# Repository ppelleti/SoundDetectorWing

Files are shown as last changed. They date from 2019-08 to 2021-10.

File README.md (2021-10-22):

This repository contains [KiCad][1] 5 files for a [FeatherWing][2]
board which lets you plug in a [SparkFun Sound Detector][3] and use it
with a Feather.  It runs the Sound Detector at 5V, and then has
voltage dividers to convert the output signals to 3.3V, for use by the
Feather.

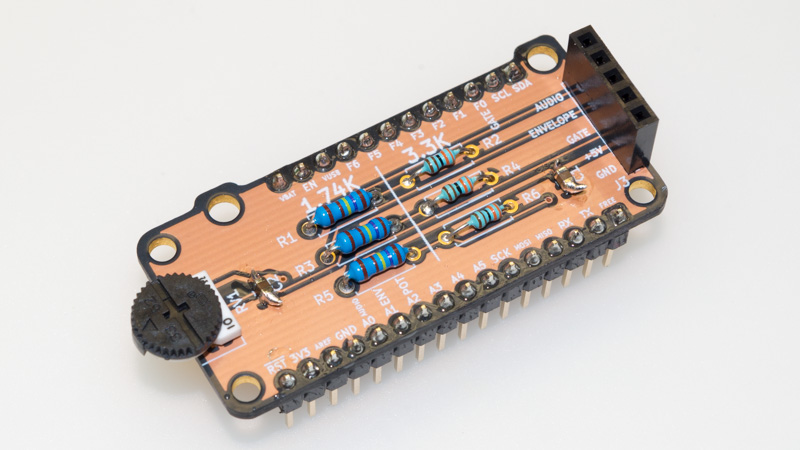
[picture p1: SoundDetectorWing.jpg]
Sound Detector FeatherWing


The "audio" analog signal is connected to feather pin A0, the
"envelope" analog signal is connected to feather pin A1, and the
"gate" digital signal is connected to the feather pin that
[I call F0][4].  There is also a potentiometer connected to feather
pin A2, which can be used, for example, if you want to implement an
adjustable threshold in software (rather than using the Sound
Detector's "gate" signal).

The board has three M2.5 mounting holes which should line up with the
Feather, and two M3 mounting holes which should line up with the Sound
Detector. There are optional places for two SMT decoupling capacitors.

SparkFun recommends running the Sound Detector at 5V, rather than
3.3V, so the Sound Detector is powered from the Feather's VUSB pin, to
get a solid 5V supply.  A consequence of this is that *this
FeatherWing will not work on battery power*; you must have USB plugged
in for power.

* [View schematic](SoundDetectorWing.pdf)
* [Order board on OSH Park][5] (photo shows the OSH Park "after dark" option)

## Bill of Materials

| Ref | Description | MPN | Digi-Key PN |
| --- | --- | --- | --- |
| C1, C2 | CAP CER 10UF 10V X5R 0805 | C0805C106K8PACTU | [399-4925-1-ND][C1] |
| J1 | 16-pin male header 2.54mm | | |
| J2 | 12-pin male header 2.54mm | | |
| J3 | CONN HDR 5POS 0.1 GOLD PCB | PPPC051LFBN-RC | [S7038-ND][J3] |
| R1, R3, R5 | RES 1.74K OHM 1/4W 1% AXIAL | MFR-25FBF52-1K74 | [1.74KXBK-ND][R1] |
| R2, R4, R6 | RES 3.3K OHM 1/4W 1% AXIAL | RNMF14FTC3K30 | [S3.3KCACT-ND][R2] |
| RV1 | POT 10K OHM THUMBWHEEL CERM ST | 3352T-1-103LF | [3352T-103LF-ND][RV1] |

[C1]: https://www.digikey.com/products/en?keywords=399-4925-1-ND
[J3]: https://www.digikey.com/products/en?keywords=S7038-ND
[R1]: https://www.digikey.com/products/en?keywords=1.74KXBK-ND
[R2]: https://www.digikey.com/products/en?keywords=S3.3KCACT-ND
[RV1]: https://www.digikey.com/products/en?keywords=3352T-103LF-ND

[1]: http://kicad.org/
[2]: https://learn.adafruit.com/adafruit-feather/feather-specification
[3]: https://www.sparkfun.com/products/12642
[4]: https://funwithsoftware.org/posts/2018-08-31-feather-ascii-art-pinout.html
[5]: https://oshpark.com/shared_projects/fDlbdMGa

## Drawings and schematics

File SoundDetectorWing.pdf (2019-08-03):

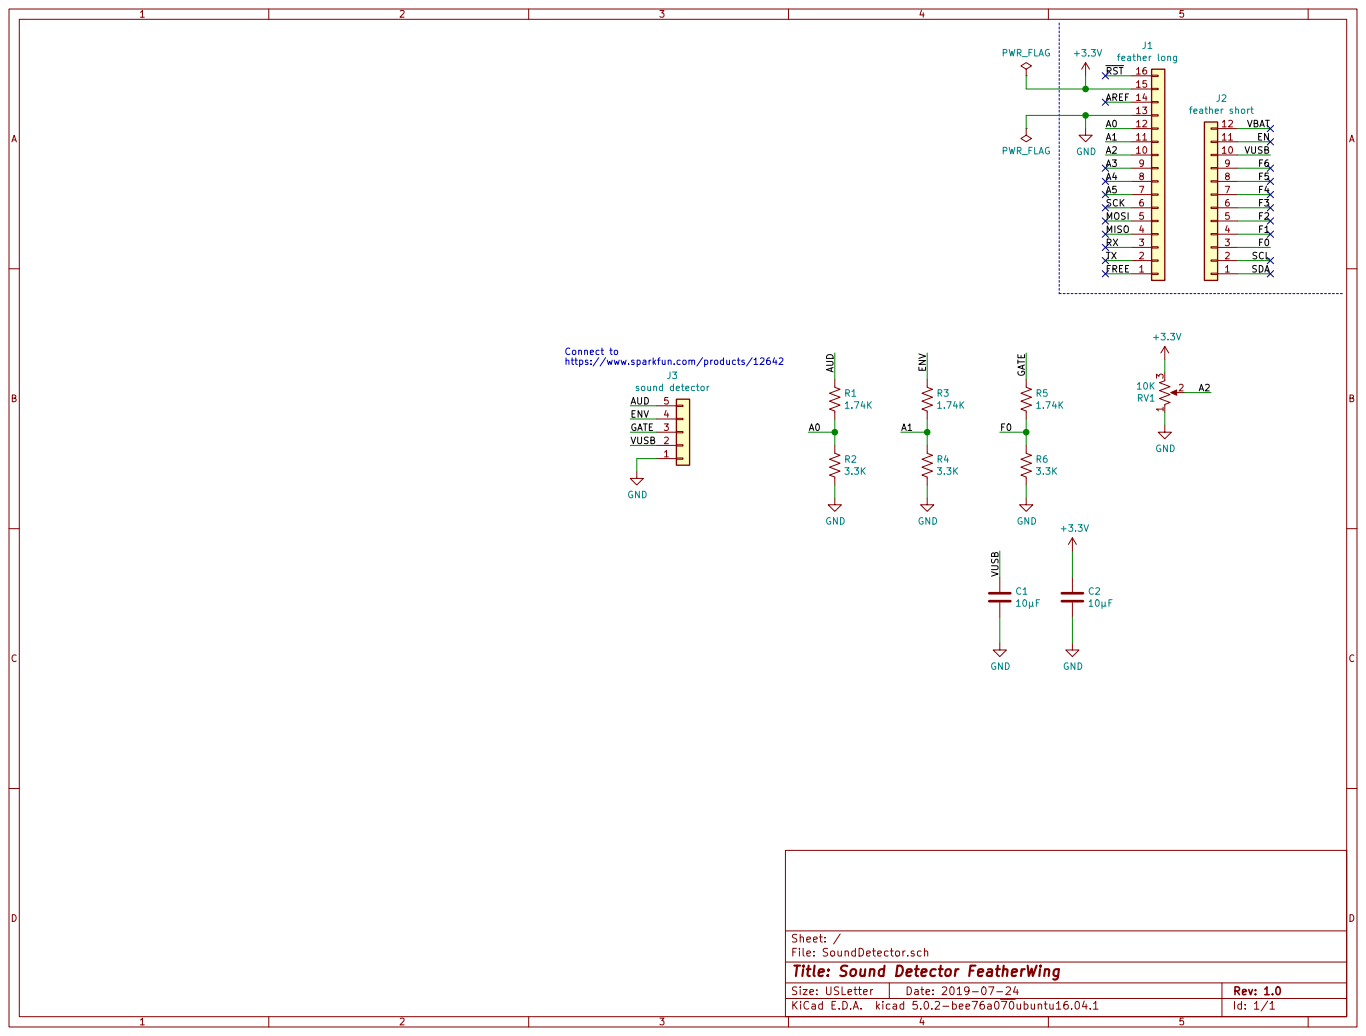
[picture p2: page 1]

+3.3V Connect to
https://www.sparkfun.com/products/12642
ENV GATE GND

File: SoundDetector.sch Sheet: /
Id: 1/1 Title: Sound Detector FeatherWing

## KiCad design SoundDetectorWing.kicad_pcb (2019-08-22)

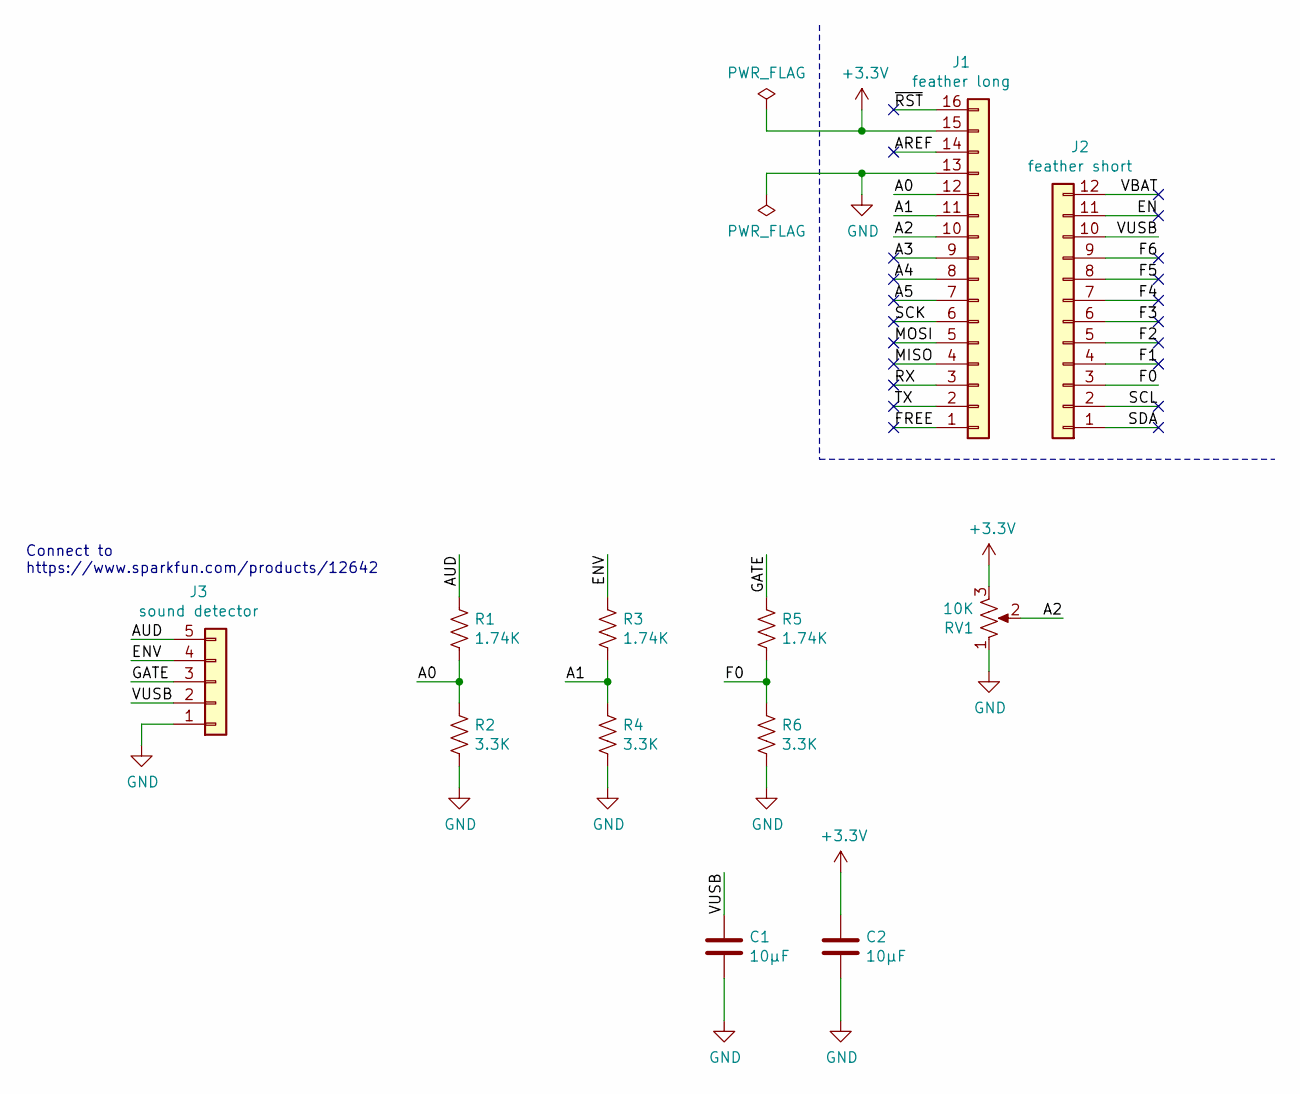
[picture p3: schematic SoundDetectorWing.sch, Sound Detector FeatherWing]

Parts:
C1, C2: 10μF; C_0805_2012Metric_Pad1.15x1.40mm_HandSolder; MPN C0805C106K8PACTU; Digi-Key_PN 399-4925-1-ND
J1: feather long; PinHeader_1x16_P2.54mm_Vertical
J2: feather short; PinHeader_1x12_P2.54mm_Vertical
J3: sound detector; PinSocket_1x05_P2.54mm_Vertical; MPN PPPC051LFBN-RC; Digi-Key_PN S7038-ND
R1, R3, R5: 1.74K; R_Axial_DIN0207_L6.3mm_D2.5mm_P7.62mm_Horizontal; MPN MFR-25FBF52-1K74; Digi-Key_PN 1.74KXBK-ND
R2, R4, R6: 3.3K; R_Axial_DIN0207_L6.3mm_D2.5mm_P7.62mm_Horizontal; MPN RNMF14FTC3K30; Digi-Key_PN S3.3KCACT-ND
RV1: 10K; Potentiometer_Bourns_3352T_Vertical; MPN 3352T-1-103LF; Digi-Key_PN 3352T-103LF-ND

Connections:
+3V3: C2.1, J1.15, RV1.3
/A0: J1.12, R1.2, R2.1
/A1: J1.11, R3.2, R4.1
/A2: J1.10, RV1.2
/A3: J1.9
/A4: J1.8
/A5: J1.7
/AREF: J1.14
/AUD: J3.5, R1.1
/EN: J2.11
/ENV: J3.4, R3.1
/F0: J2.3, R5.2, R6.1
/F1: J2.4
/F2: J2.5
/F3: J2.6
/F4: J2.7
/F5: J2.8
/F6: J2.9
/FREE: J1.1
/GATE: J3.3, R5.1
/MISO: J1.4
/MOSI: J1.5
/RX: J1.3
/SCK: J1.6
/SCL: J2.2
/SDA: J2.1
/TX: J1.2
/VBAT: J2.12
/VUSB: C1.1, J2.10, J3.2
/~RST: J1.16
GND: C1.2, C2.2, J1.13, J3.1, R2.2, R4.2, R6.2, RV1.1

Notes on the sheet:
Connect to https://www.sparkfun.com/products/12642

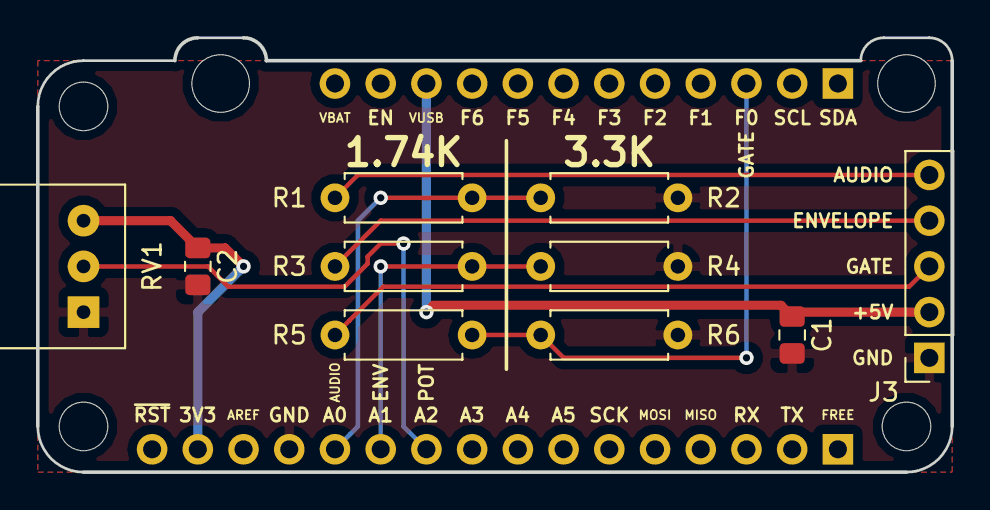
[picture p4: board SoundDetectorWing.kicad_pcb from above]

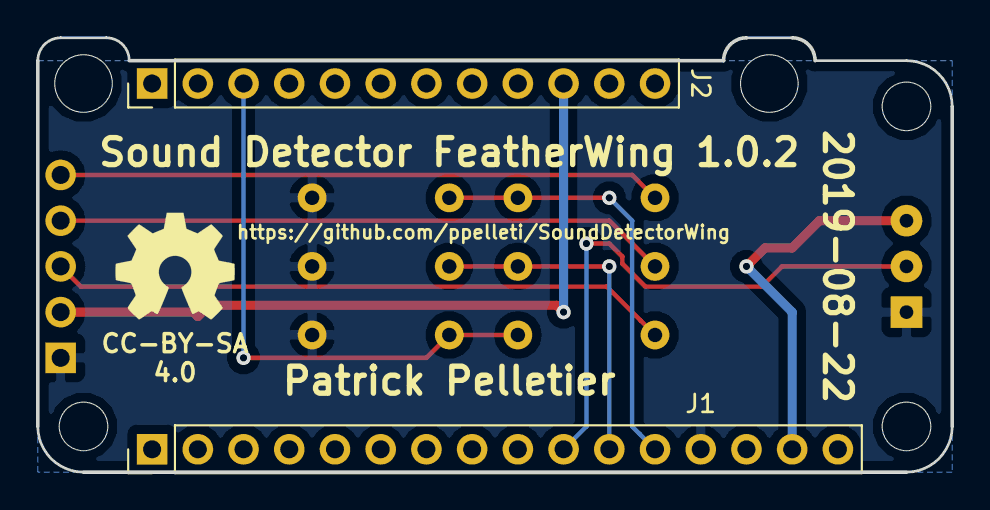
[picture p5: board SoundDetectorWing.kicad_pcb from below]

Board: 2 copper layers, 50.8 x 24.1 mm, 12 parts (2 on the bottom side), 10 nets.

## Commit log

2019-07-24 Initial commit.
    [SoundDetector.kicad_pcb, SoundDetector.sch]
2019-07-24 Draw schematic.
    [SoundDetector.sch]
2019-07-24 Use VUSB instead of +5V.
    [SoundDetector.sch]
2019-07-24 Got it passing ERC.
    [SoundDetector.sch]
2019-07-24 Add a couple decouplng capacitors, in case they are needed.
    [SoundDetector.sch]
2019-07-24 Assign footprints.
    [SoundDetector.sch]
2019-07-24 Add thumbwheel potentiometer footprint.
2019-07-24 Assign potentiometer footprint.
    [SoundDetector.sch]
2019-07-24 Import new footprints into PCB.
    [SoundDetector.kicad_pcb]
2019-07-24 Position footprints on PCB.
    [SoundDetector.kicad_pcb]
2019-07-24 Draw all the tracks.
    [SoundDetector.kicad_pcb]
2019-07-24 Fill GND zones.
    [SoundDetector.kicad_pcb]
2019-07-24 Add information on back silkscreen.
    [SoundDetector.kicad_pcb]
2019-07-24 Add metadata to schematic.
    [SoundDetector.sch]
2019-07-24 Put GitHub URL on silkscreen.
    [SoundDetector.kicad_pcb]
2019-08-03 Add PDF of schematic.
2019-08-09 Add screw holes to line up with SparkFun Sound Detector board.
    [SoundDetectorWing.kicad_pcb]
2019-08-09 Label the functions of the feather pins.
    [SoundDetectorWing.kicad_pcb]
2019-08-22 Finally get SoundDetector mounting holes in correct place.
    [SoundDetectorWing.kicad_pcb]
2019-08-22 Adjust board outline.
    [SoundDetectorWing.kicad_pcb]
2019-08-22 Update version number.
    [SoundDetectorWing.kicad_pcb]
2019-09-09 Add BOM.
2019-10-02 Link to board on OSH Park.
2019-10-02 Mention that USB power is required.
2019-10-02 Ugh, "y" in battery.
2021-10-22 Link to kicad.org
    https://forum.kicad.info/t/warning-avoid-all-links-to-kicad-pcb-org-use-kicad-org/31521

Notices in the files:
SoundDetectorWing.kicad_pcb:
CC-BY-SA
